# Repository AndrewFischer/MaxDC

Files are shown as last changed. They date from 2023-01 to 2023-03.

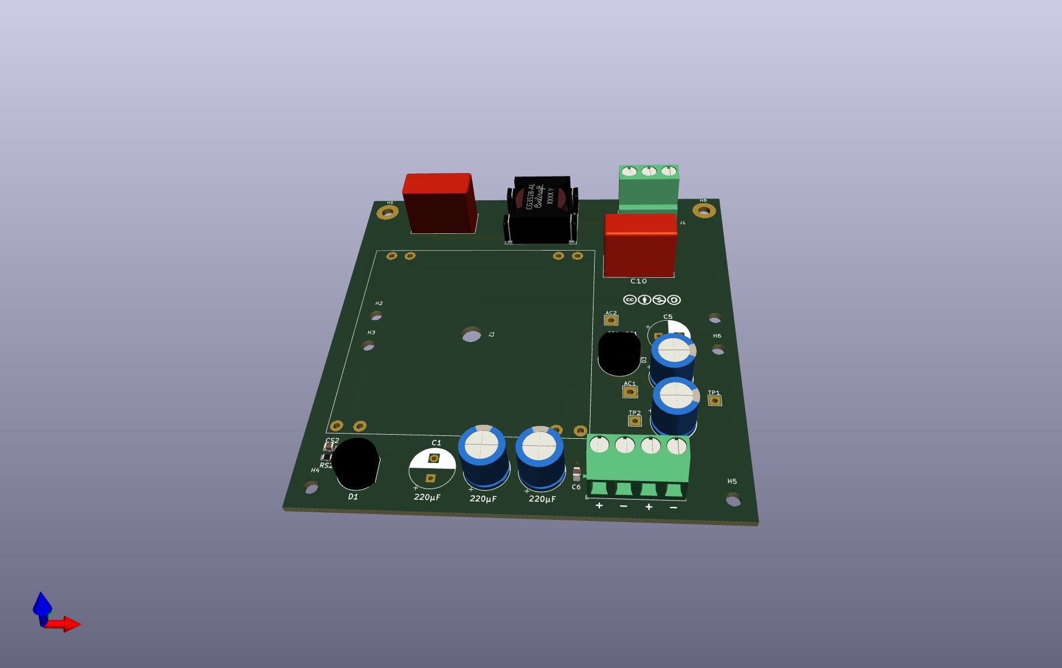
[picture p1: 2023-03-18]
Images/MaxDC.png

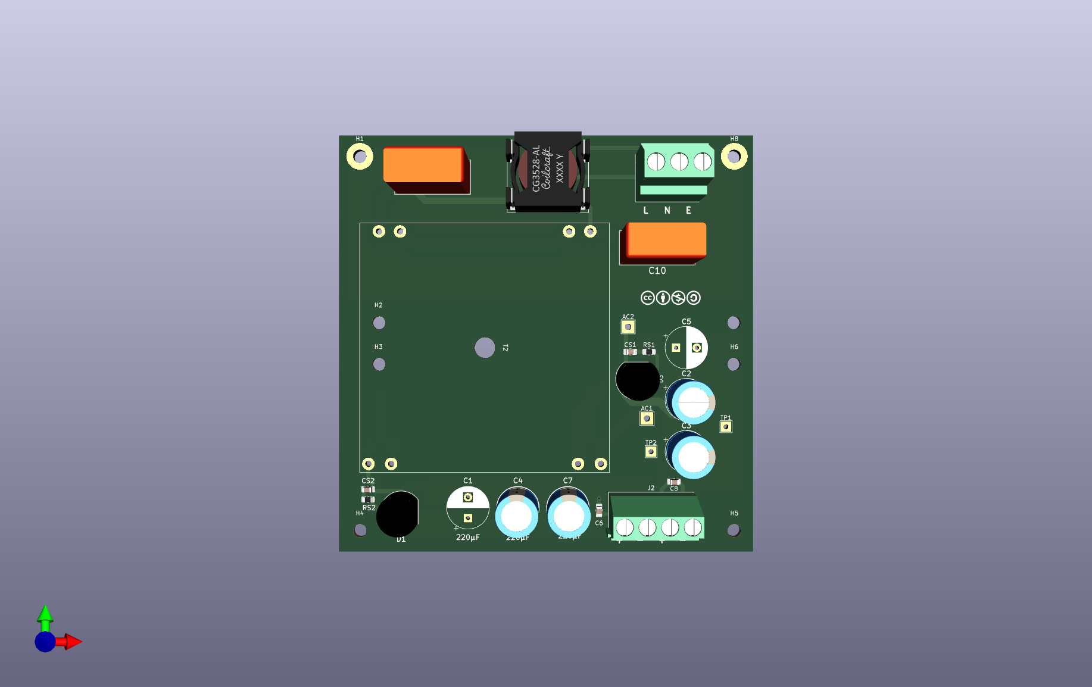
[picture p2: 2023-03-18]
Images/MaxDC_PCB.png

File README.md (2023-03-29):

# MaxDC
Unregulated Dual Linear Power Supply.

The 99.5x100mm Board fits in a Hammond 1455N1201 or 1202 case. The case is 20mm longer then the PCB which leaves room for connections.  
T1 is a 25VA Telema 7006xK. The 15VA 7005xK have the same foot print.

C9 and C10 must be rated for Class-Y line to ground use.  
Optional parts RS1, RS2, CS1 and CS2 form snubbers. See [snubber.pdf](Datasheets/snubber.pdf) in the Datasheets folder for details on selecting values.

<br>  
:exclamation: Danger of electric shock. 240Volts AC is present on this board. A suitable enclosure is required for safe operation.<br>
:warning: The files embodied in this repository are provided to you "as-is" and without warranty of any kind, express, implied or otherwise, including without limitation, any warranty of fitness for a particular purpose. See section 5 of the license.<br>
**This project is untested.**

### License
[cc-by-nc 4.0](LICENSE.md)

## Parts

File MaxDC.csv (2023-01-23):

Comment | Designator | Footprint | LCSC
1nF | C6,C8 | Capacitor_SMD:C_0805_2012Metric_Pad1.18x1.45mm_HandSolder | C46653
130pF | CS1,CS2 | Capacitor_SMD:C_0805_2012Metric_Pad1.18x1.45mm_HandSolder | C520003
1.69K | RS1,RS2 | Resistor_SMD:R_0805_2012Metric_Pad1.20x1.40mm_HandSolder | C170810

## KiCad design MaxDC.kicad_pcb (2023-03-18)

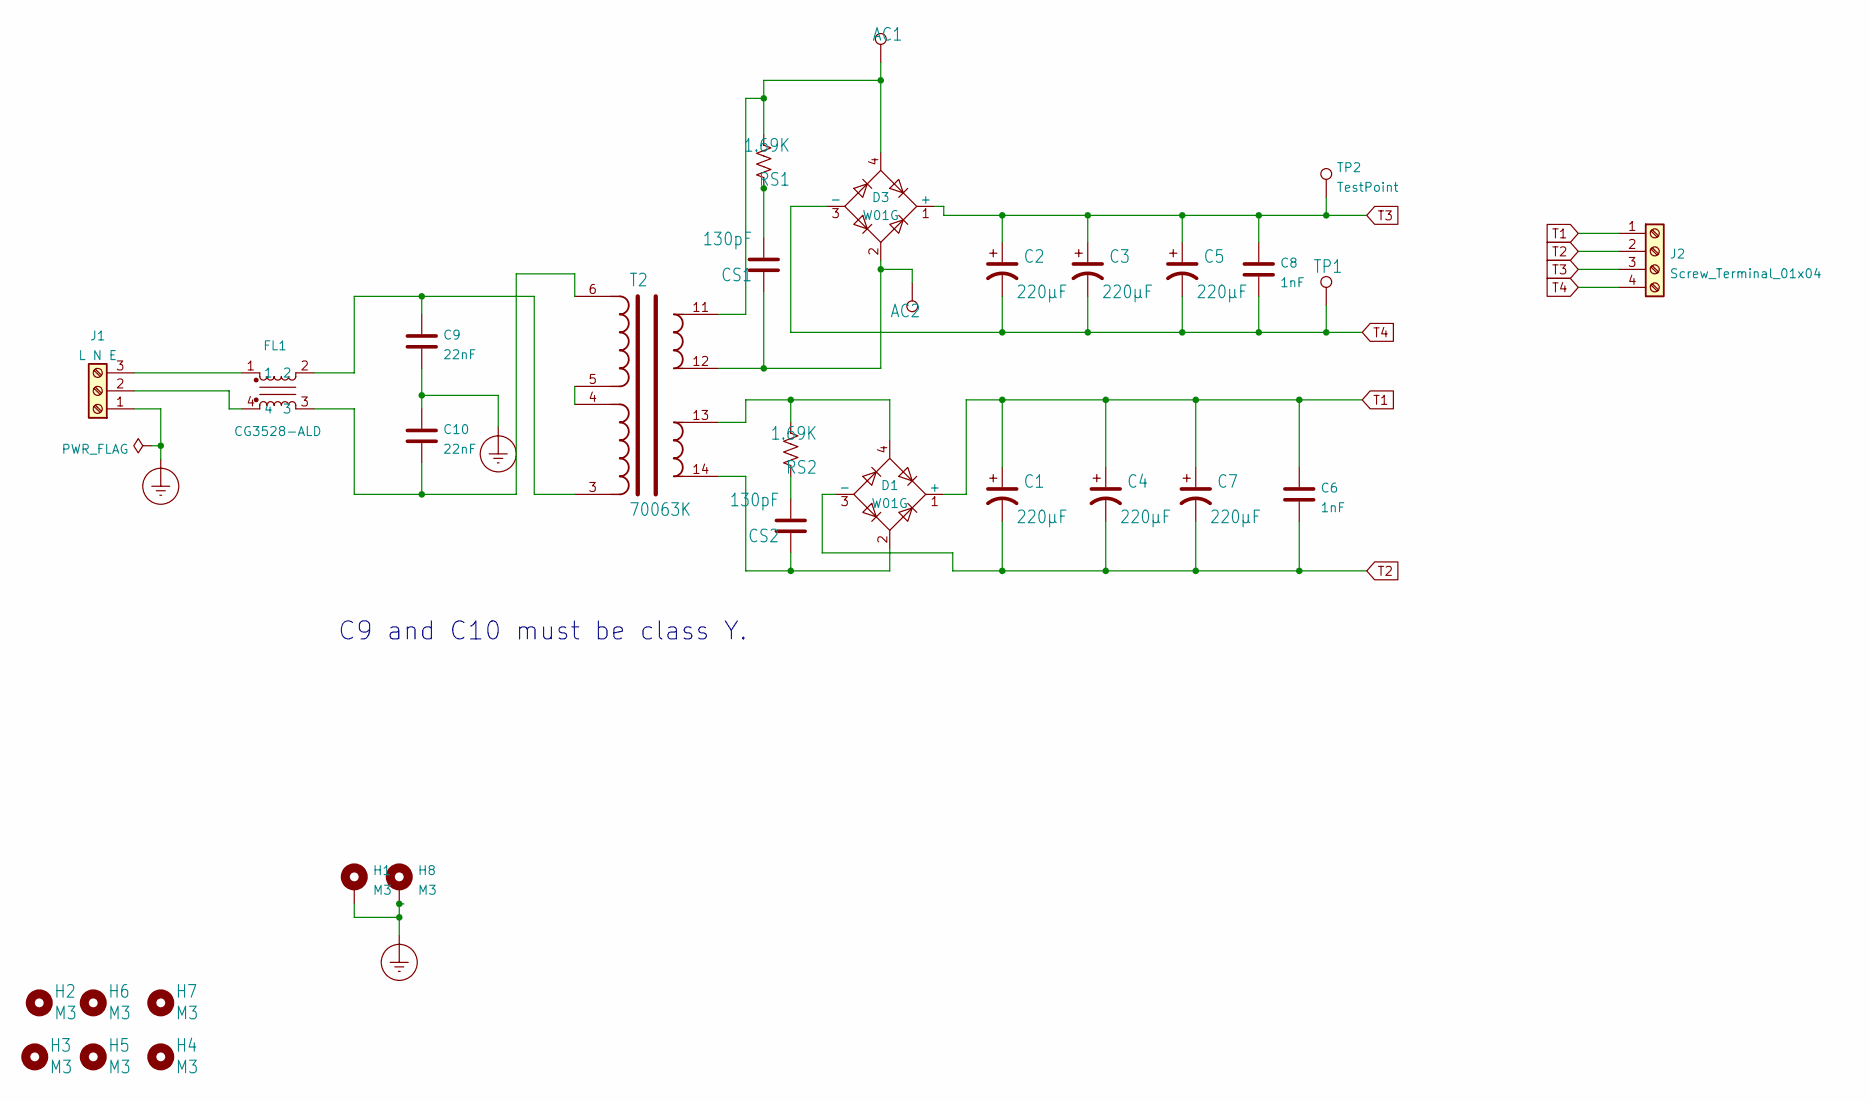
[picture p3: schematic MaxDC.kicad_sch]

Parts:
AC1, AC2: SE13; TestPoint_THTPad_3.0x3.0mm_Drill1.5mm
C1, C2, C3, C4, C5, C7: 220µF; CP_Radial_D10.0mm_P5.00mm; MPN UPW1H221MPD
C6, C8: 1nF; C_0805_2012Metric_Pad1.18x1.45mm_HandSolder; MPN CL21B102KBCNNNC; LCSC C46653
C9: 22nF; C_Rect_L18.0mm_W8.0mm_P15.00mm_FKS3_FKP3; MPN Kemet R413I222050M1M
C10: 22nF; C_Rect_L18.0mm_W8.0mm_P15.00mm_FKS3_FKP3; MPN R413I222050M1M
CS1, CS2: 130pF; C_0805_2012Metric_Pad1.18x1.45mm_HandSolder; MPN CC0805JRNPO9BN131; LCSC C520003
D1, D3: W01G; Diode_Bridge_Round_D9.8mm
FL1: CG3528-ALD; L_CoilCraft_CG3528AL
H1, H8: M3; MountingHole_3.2mm_M3_Pad
H2, H3, H4, H5, H6, H7: M3; MountingHole_3.2mm_M3
J1: L N E; TerminalBlock_Phoenix_MKDS-3-3-5.08_1x03_P5.08mm_Horizontal
J2: Screw_Terminal_01x04; TerminalBlock_Phoenix_MKDS-1,5-4-5.08_1x04_P5.08mm_Horizont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
RS1, RS2: 1.69K; R_0805_2012Metric_Pad1.20x1.40mm_HandSolder; MPN WR08X1691FTL; LCSC C170810
T2: 70063K; 70060K
TP1: SE13; TestPoint_THTPad_2.5x2.5mm_Drill1.2mm
TP2: TestPoint; TestPoint_THTPad_2.5x2.5mm_Drill1.2mm

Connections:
Earth_Protective: C9.2, C10.1, H1.1, H8.1, J1.1
unnamed: AC1.1, D3.4, RS1.2, T2.11
unnamed: AC2.1, CS1.1, D3.2, T2.12
unnamed: C9.1, FL1.2, T2.3
unnamed: C10.2, FL1.3, T2.6
unnamed: CS1.2, RS1.1
unnamed: CS2.1, D1.2, T2.14
unnamed: CS2.2, RS2.1
unnamed: D1.4, RS2.2, T2.13
unnamed: FL1.1, J1.3
unnamed: FL1.4, J1.2
unnamed: T2.4, T2.5
T1: C1.1, C4.1, C6.2, C7.1, D1.1 (+), J2.1
T2: C1.2, C4.2, C6.1, C7.2, D1.3 (-), J2.2
T3: C2.1, C3.1, C5.1, C8.2, D3.1 (+), J2.3, TP2.1
T4: C2.2, C3.2, C5.2, C8.1, D3.3 (-), J2.4, TP1.1

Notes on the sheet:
C9 and C10 must be class Y.

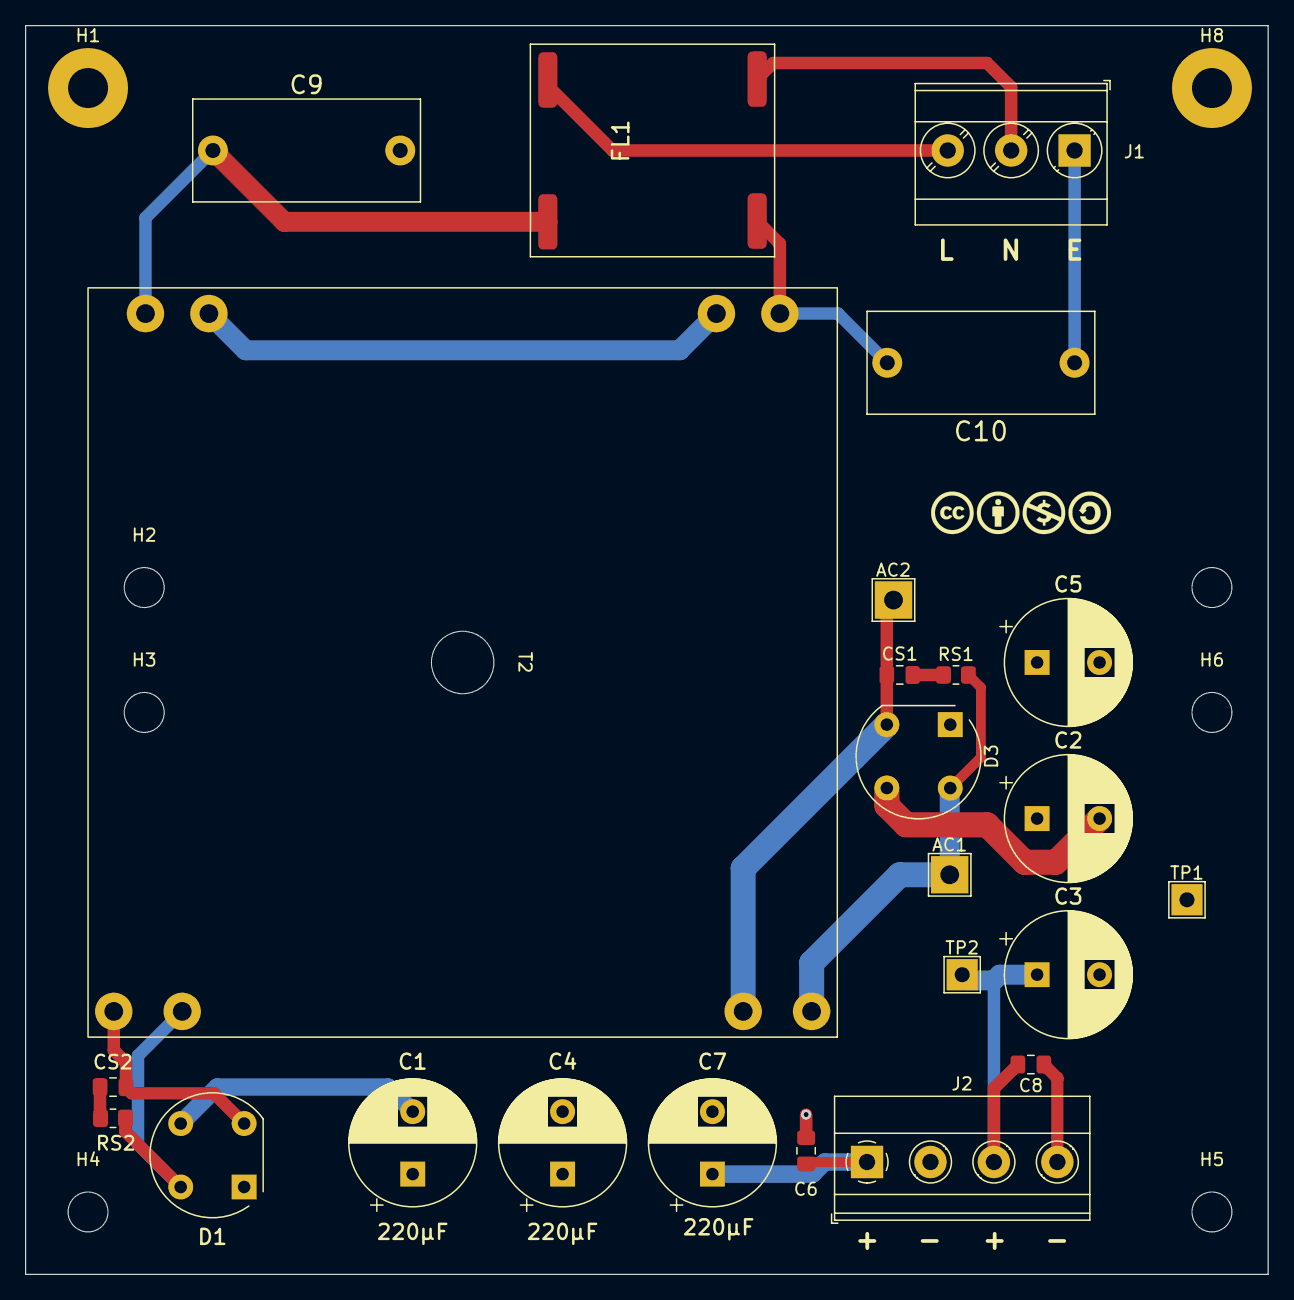
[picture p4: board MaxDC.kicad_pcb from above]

Board: 2 copper layers, 99.5 x 100.0 mm, 32 parts (0 on the bottom side), 16 nets.

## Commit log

2023-01-23 Add files via upload
    Fix symbol library path. CoilCraft symbol lib is now local to project.
    Respin PCB with CC By-NC logo and 240VAC warning
    [MaxDC.kicad_pcb, MaxDC.kicad_sch]
2023-01-24 Add files via upload
    Begin Changes for creepage. Reverse N and E input terminals.
    [MaxDC.kicad_pcb, MaxDC.kicad_sch]
2023-01-24 Add files via upload
    Adjust placement and spacing for 240VAC safety. Slots not needed.
    [MaxDC-B_Cu.gbl, MaxDC-B_Mask.gbs, MaxDC-B_Paste.gbp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]
2023-01-27 Add files via upload
    Rev 0.3 adjusts the board layout to fit inside a Hammond 1455 series enclosure. Move components and line voltage traces in from the edges of the PCB.
    [MaxDC.kicad_pcb]
2023-01-28 Add files via upload
    28012023 Uploaded to JLCPCB
    [MaxDC.csv, MaxDC.kicad_pcb, MaxDC.kicad_sch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]
2023-01-30 Add files via upload
    Add Front Panel Design files. 1544N120x.fpd is a blank end panel for a Hammon 1455N case. MaxDCFront is the front panel.
2023-01-31 Add files via upload
    Correct 3.95mm corner radius.
2023-02-05 Add files via upload
    Uploaded to JLC. Branch ready to merge back to main.
    Move edge to the left and change width to 99.5mm. After checking a 100mm board in a 1455 case, I made this board .5mm wider. Move the edges to give the transformer a little more clearance.
    Moved the caps at the bottom of the board up 1mm. That is to give more clearance for output connectors. 5-way binding posts should clear, but this gives a little more leeway.
    [MaxDC-B_Cu.gbl, MaxDC-B_Mask.gbs, MaxDC-B_Paste.gbp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]
2023-03-18 Better 3D render of PCB
    [MaxDC.kicad_pcb]

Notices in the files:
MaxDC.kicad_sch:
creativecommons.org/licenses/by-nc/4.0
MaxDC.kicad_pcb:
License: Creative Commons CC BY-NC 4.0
